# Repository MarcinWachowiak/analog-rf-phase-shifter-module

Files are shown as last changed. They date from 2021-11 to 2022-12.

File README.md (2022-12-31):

# Analog RF phase shifter module
<div align="justify">
Analog RF phase shifter modules for 2.45 GHz or 5.8 GHz. Phase shift range up to 360° for input voltage of 0 - 3.3V

**There is a discrepancy between the simulation results and testbed measurements. 
A more detailed analysis of parasitics and fine-tuning of component values is advised.**
</div>

  - **2.45 GHz distributed components version**

    **Manufactured prototypes:**

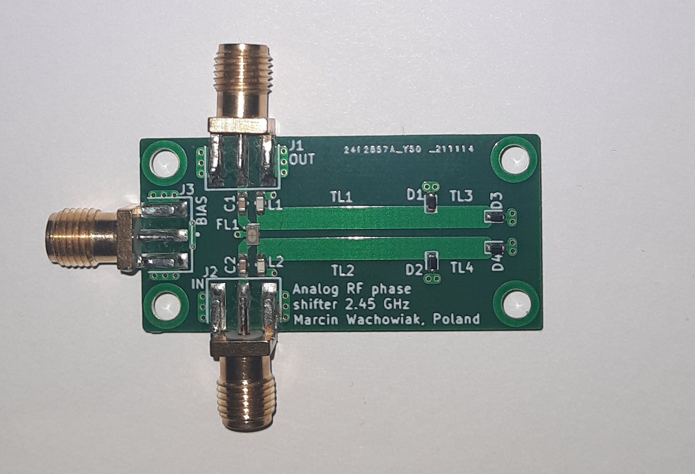
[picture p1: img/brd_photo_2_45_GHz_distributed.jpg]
brd_photo
    

    **PCB:**
    
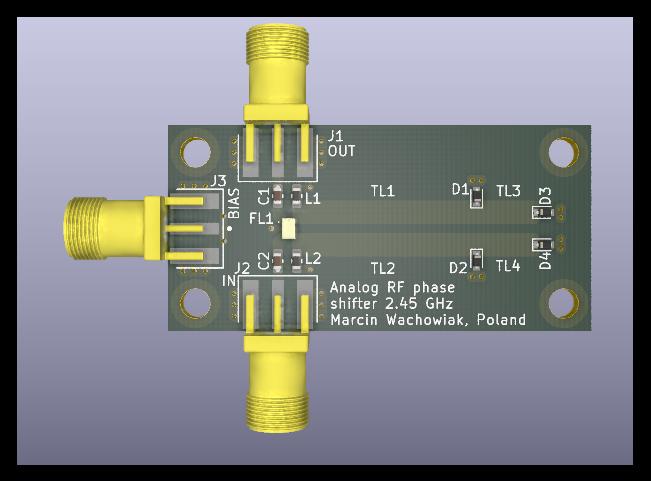
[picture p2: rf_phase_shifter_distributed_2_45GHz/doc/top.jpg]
    
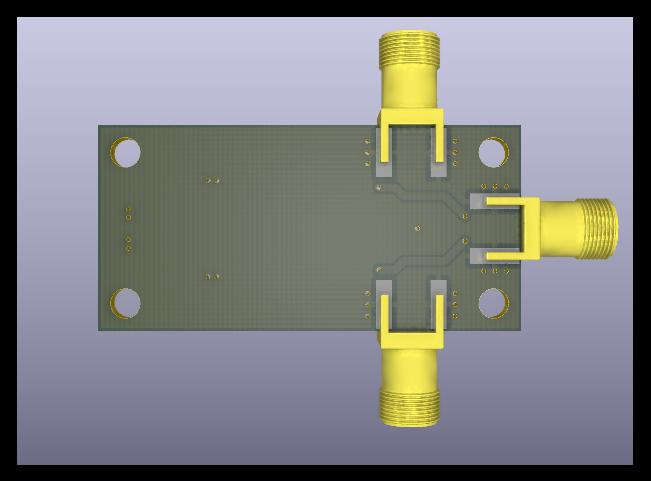
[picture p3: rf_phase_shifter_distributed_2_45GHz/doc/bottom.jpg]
2_45GHz_bottom
    

    **Simualtion results:**
    
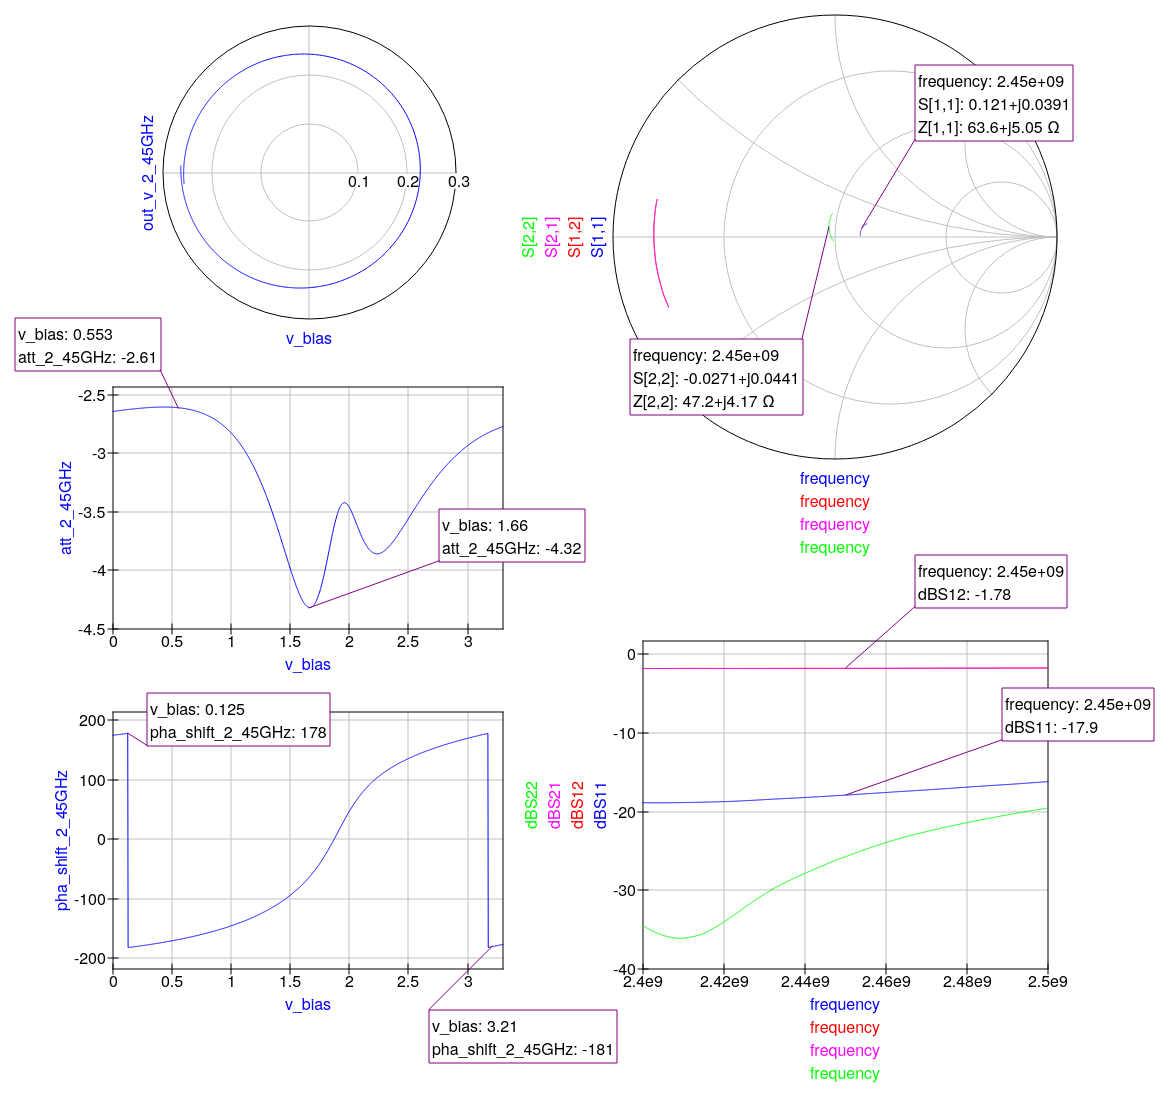
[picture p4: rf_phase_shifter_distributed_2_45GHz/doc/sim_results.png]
simulation_results_2_45GHz
    

    <br>

  - **2.45 GHz discrete components version**

    **Manufactured prototypes:**

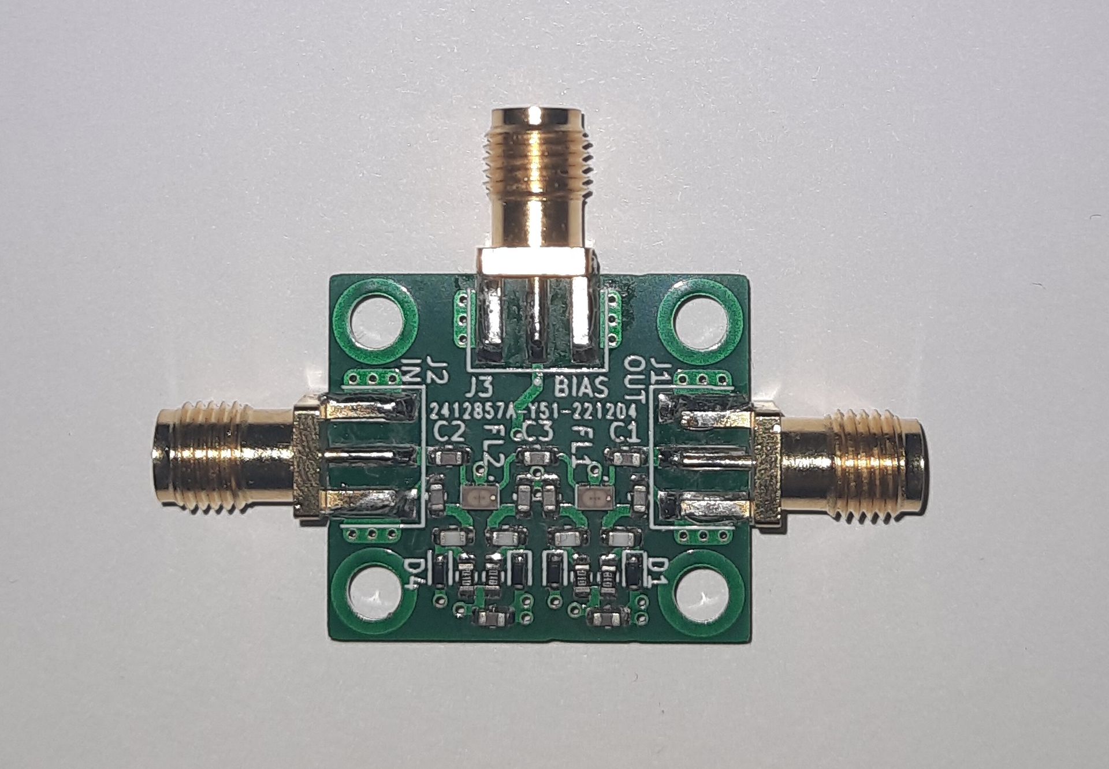
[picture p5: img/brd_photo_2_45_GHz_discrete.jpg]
brd_photo
    

    **PCB:**
    
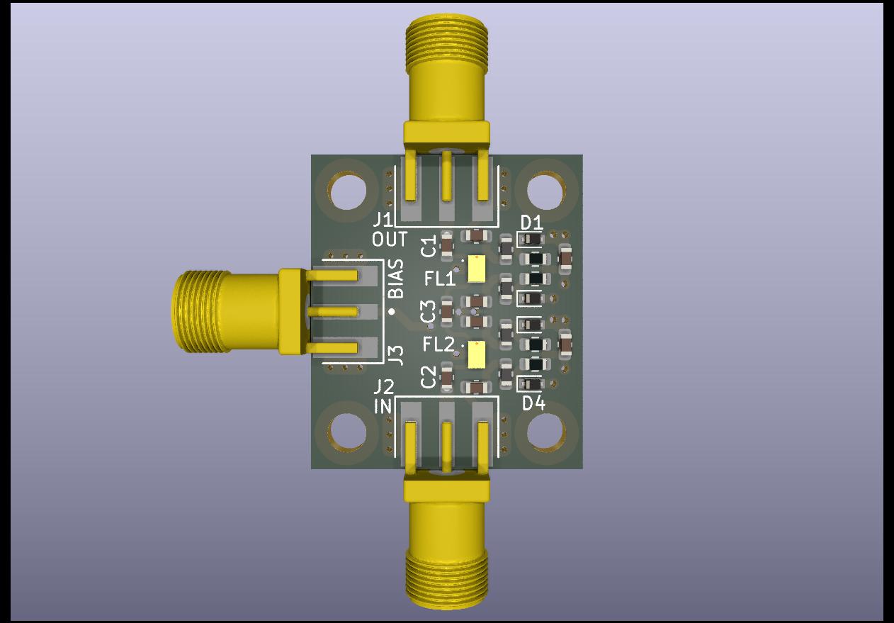
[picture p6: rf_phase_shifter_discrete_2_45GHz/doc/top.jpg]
    
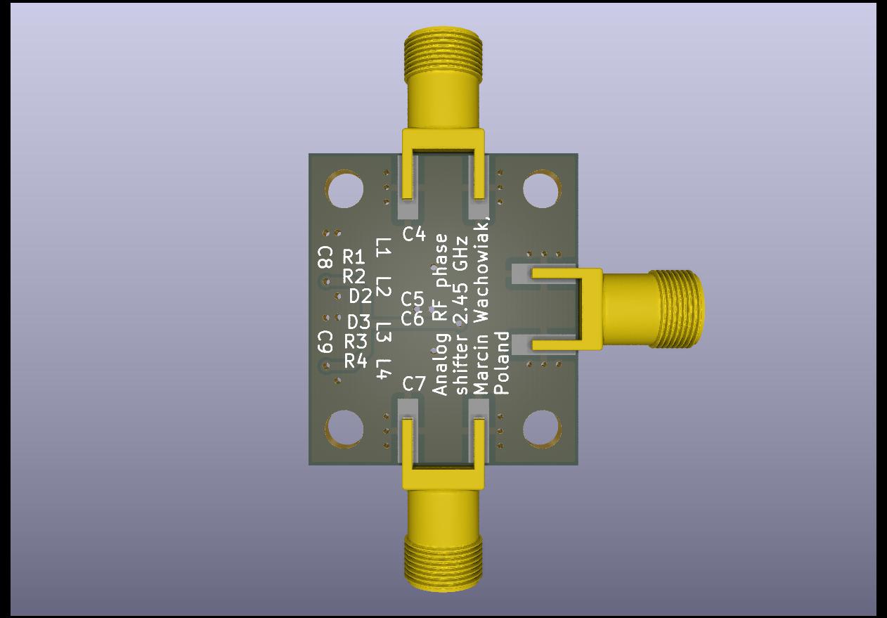
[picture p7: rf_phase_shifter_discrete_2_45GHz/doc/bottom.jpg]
2_45GHz_bottom
    

    **Simualtion results:**
    
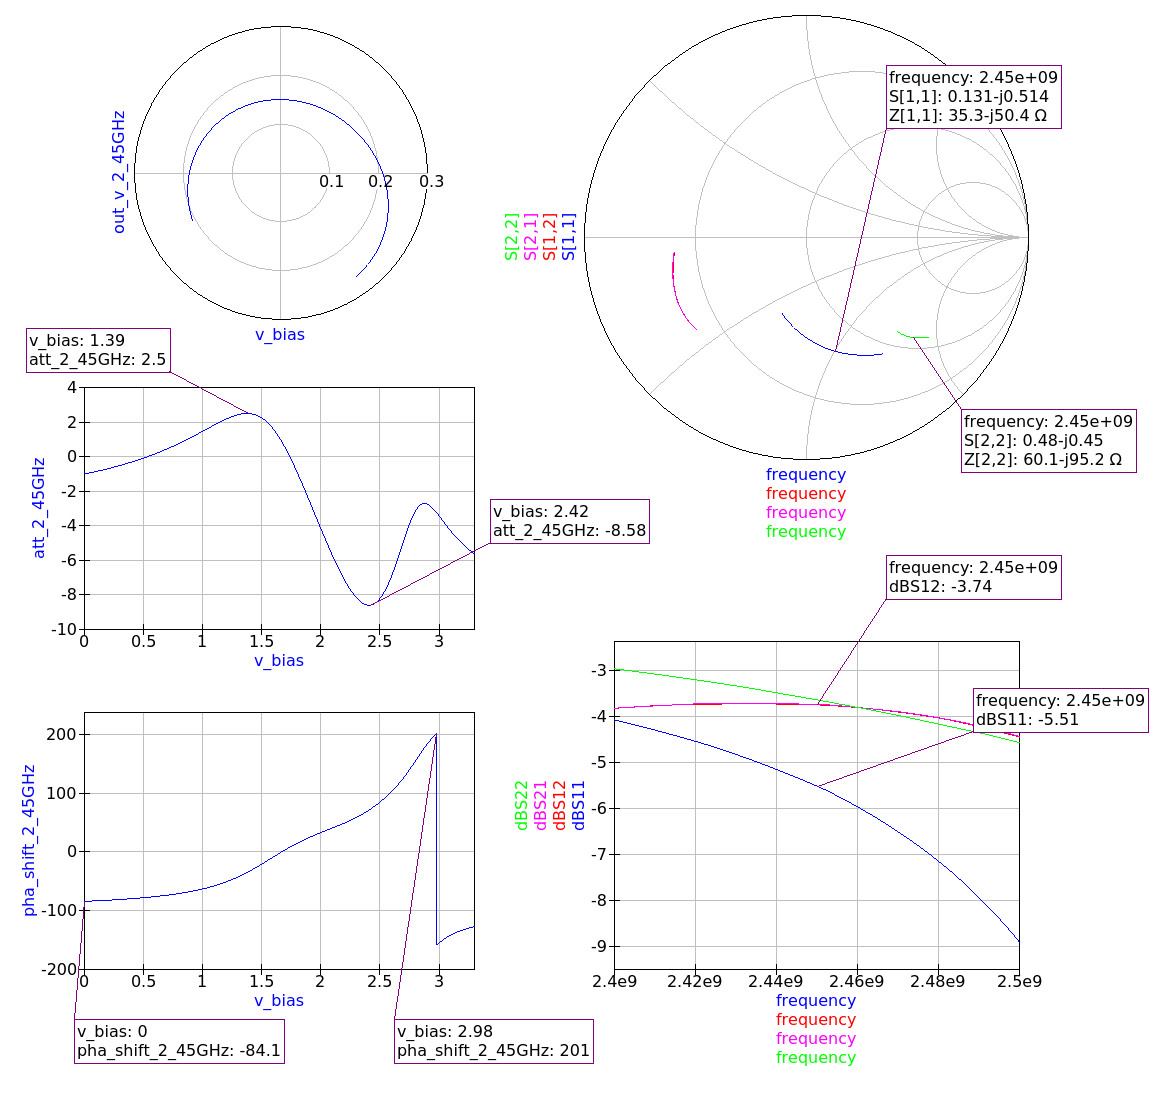
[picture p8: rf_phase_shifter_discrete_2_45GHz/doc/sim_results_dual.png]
simulation_results_2_45GHz
    

    <br>

  - **5.8 GHz distributed components version**

    **Manufactured prototypes:**

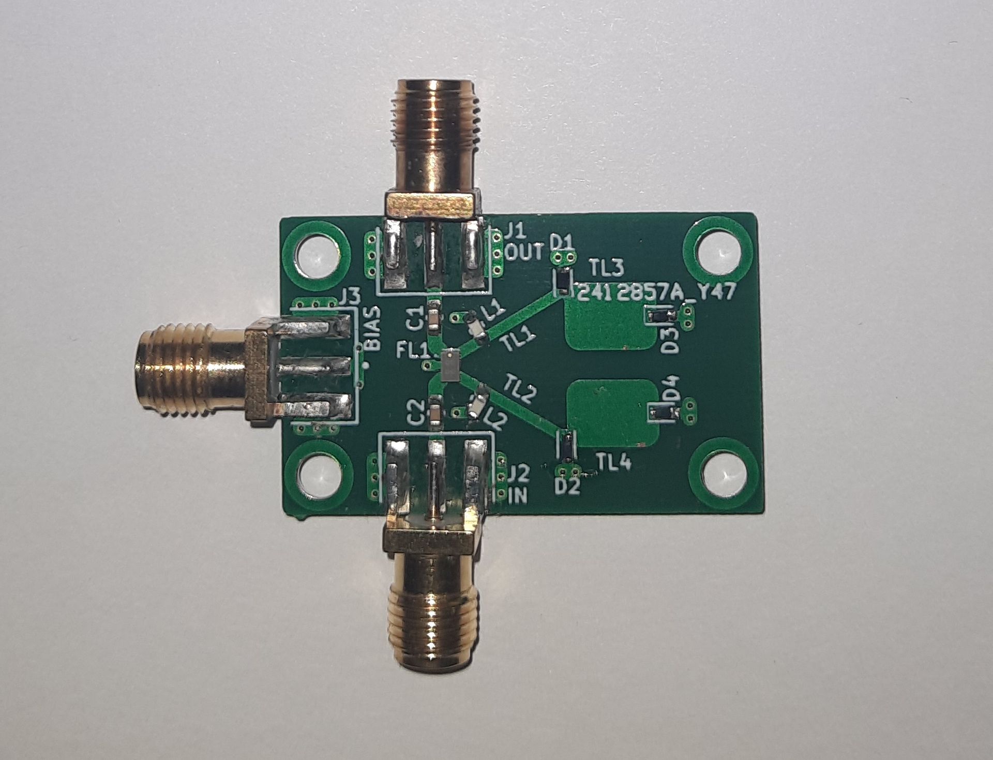
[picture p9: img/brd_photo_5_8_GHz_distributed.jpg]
brd_photo
    

    **PCB:**
    
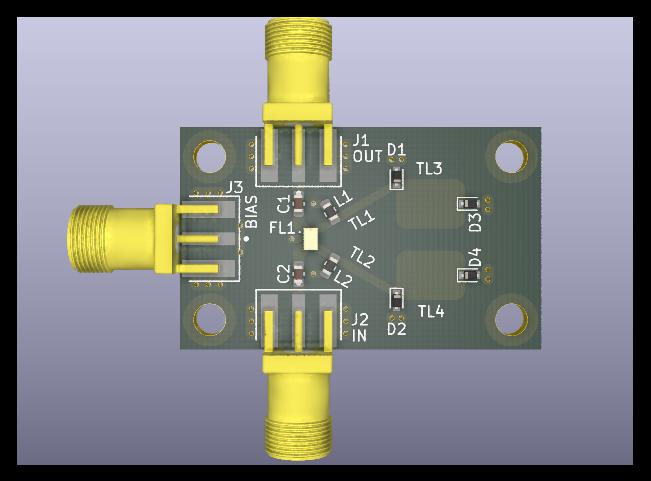
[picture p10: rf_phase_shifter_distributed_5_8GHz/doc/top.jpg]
5_8GHz_top
    
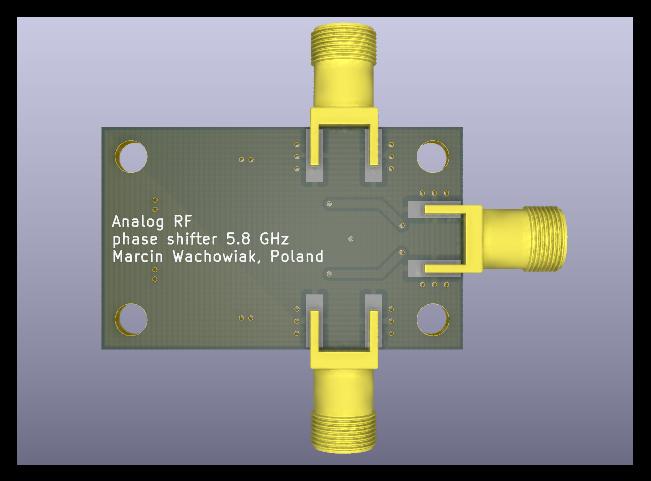
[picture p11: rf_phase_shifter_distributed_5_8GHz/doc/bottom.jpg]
5_8GHz_bottom
    

    **Simualtion results:**

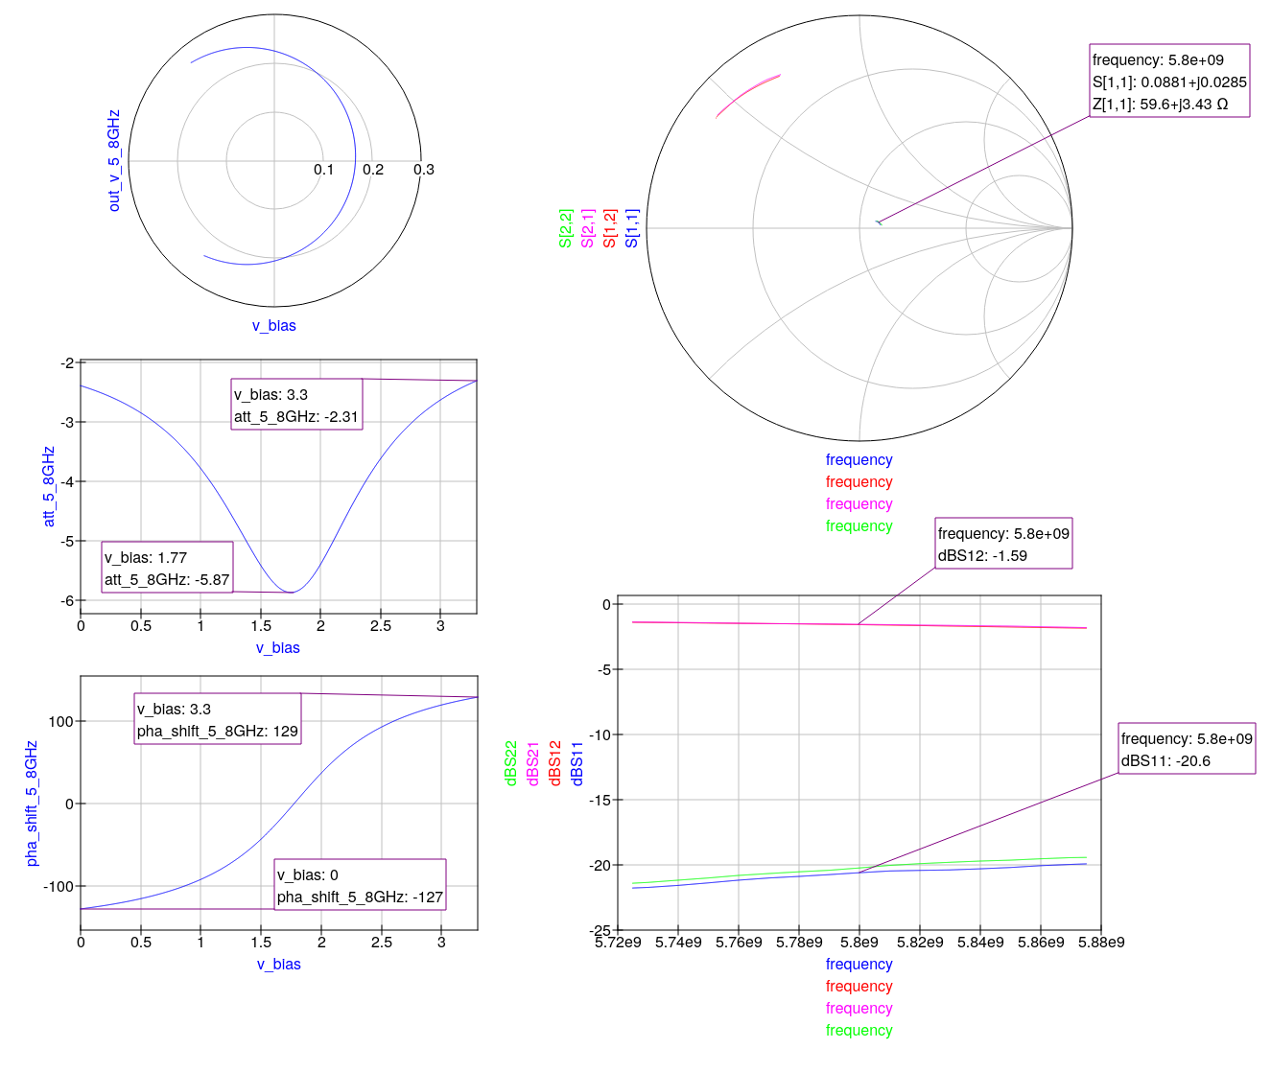
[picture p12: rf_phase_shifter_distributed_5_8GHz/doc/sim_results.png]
simulation_results_5_8GHz


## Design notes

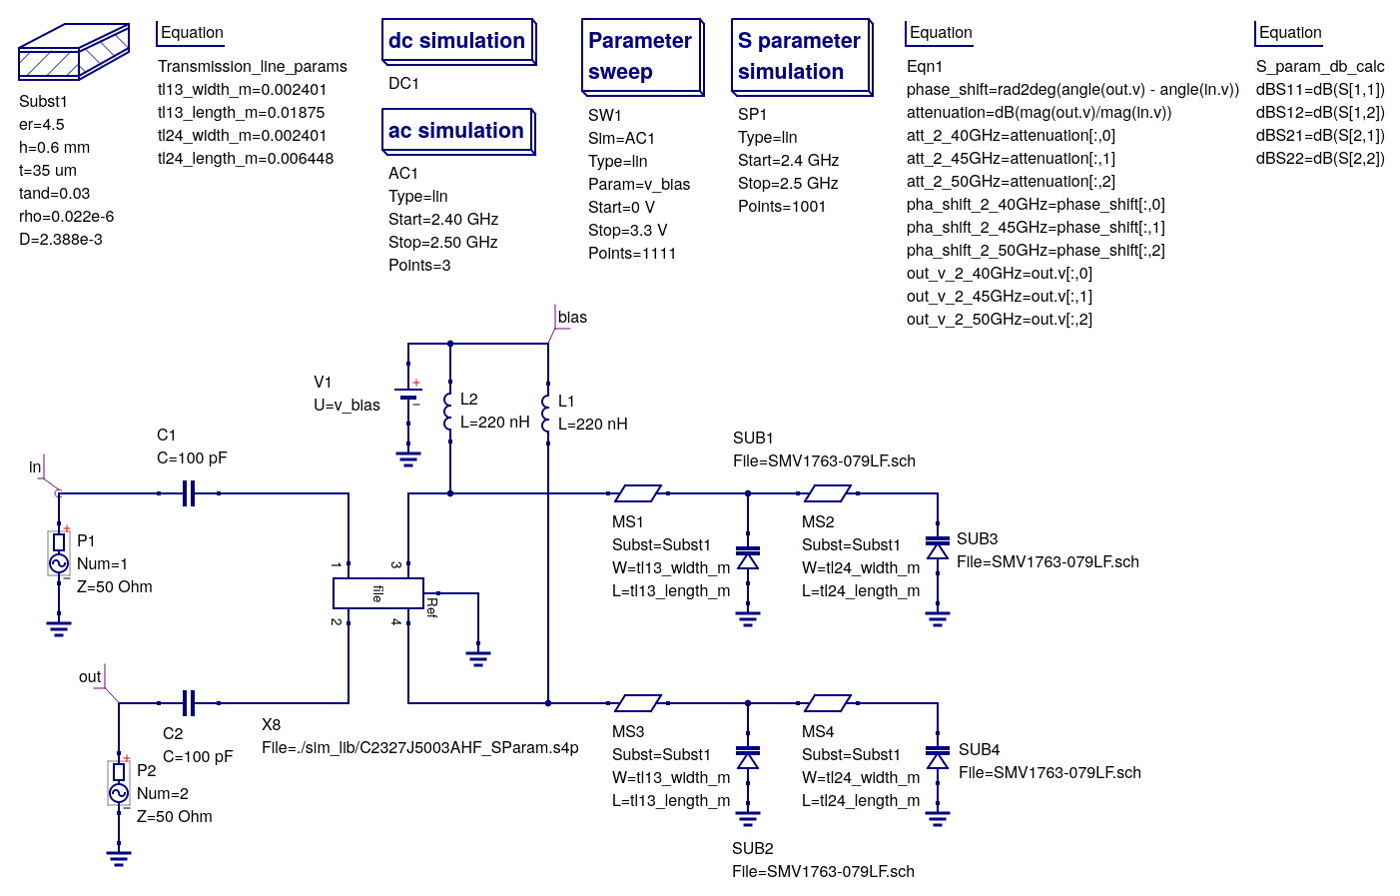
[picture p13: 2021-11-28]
rf_phase_shifter_distributed_2_45GHz/doc/sim_sch.png

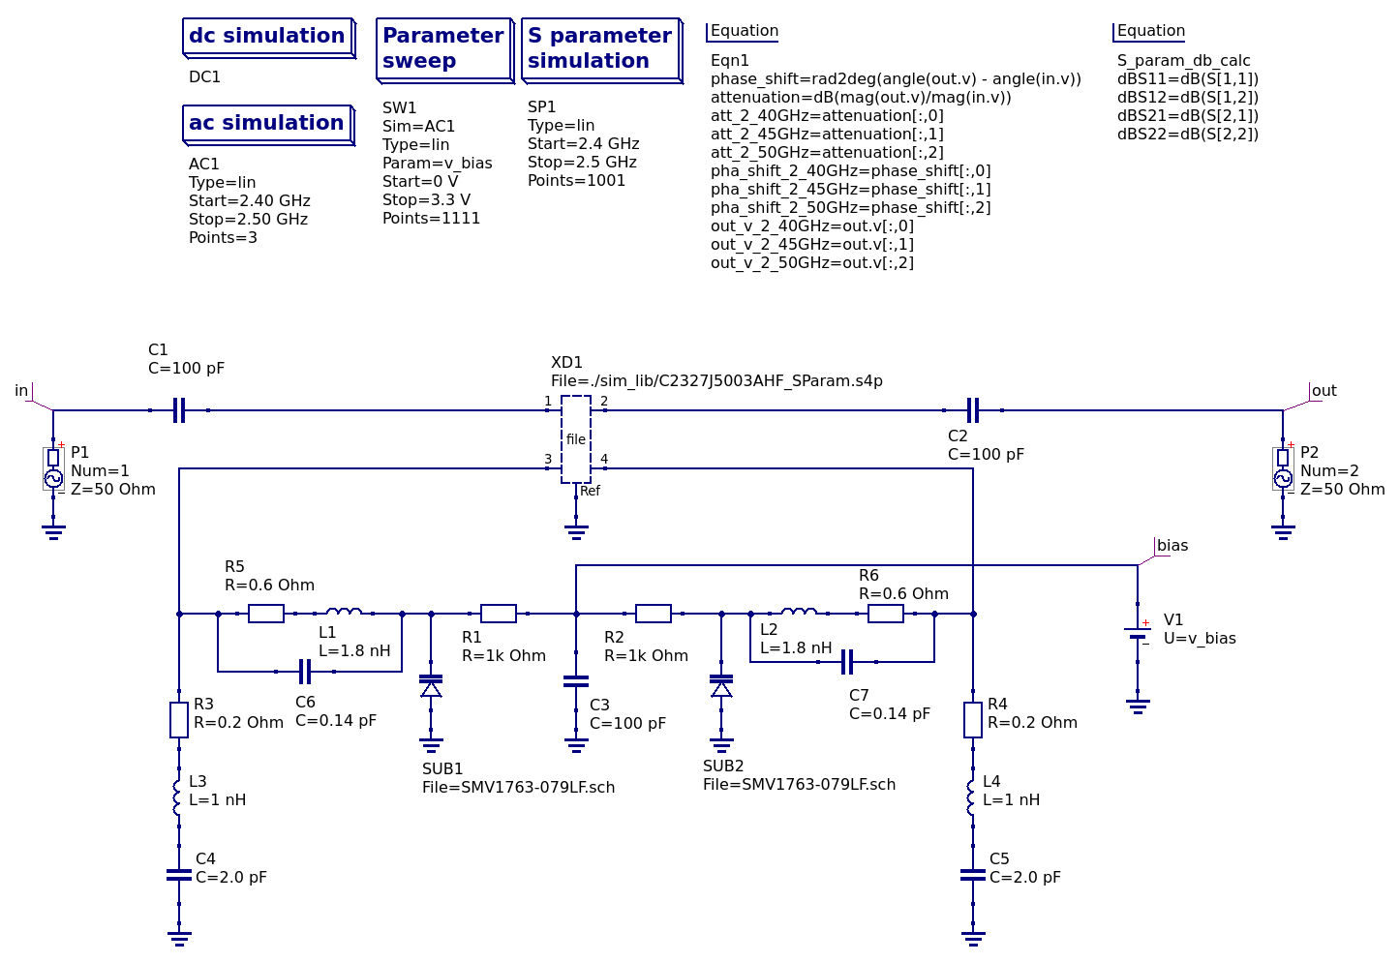
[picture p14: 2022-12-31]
rf_phase_shifter_discrete_2_45GHz/doc/sim_sch_single.png

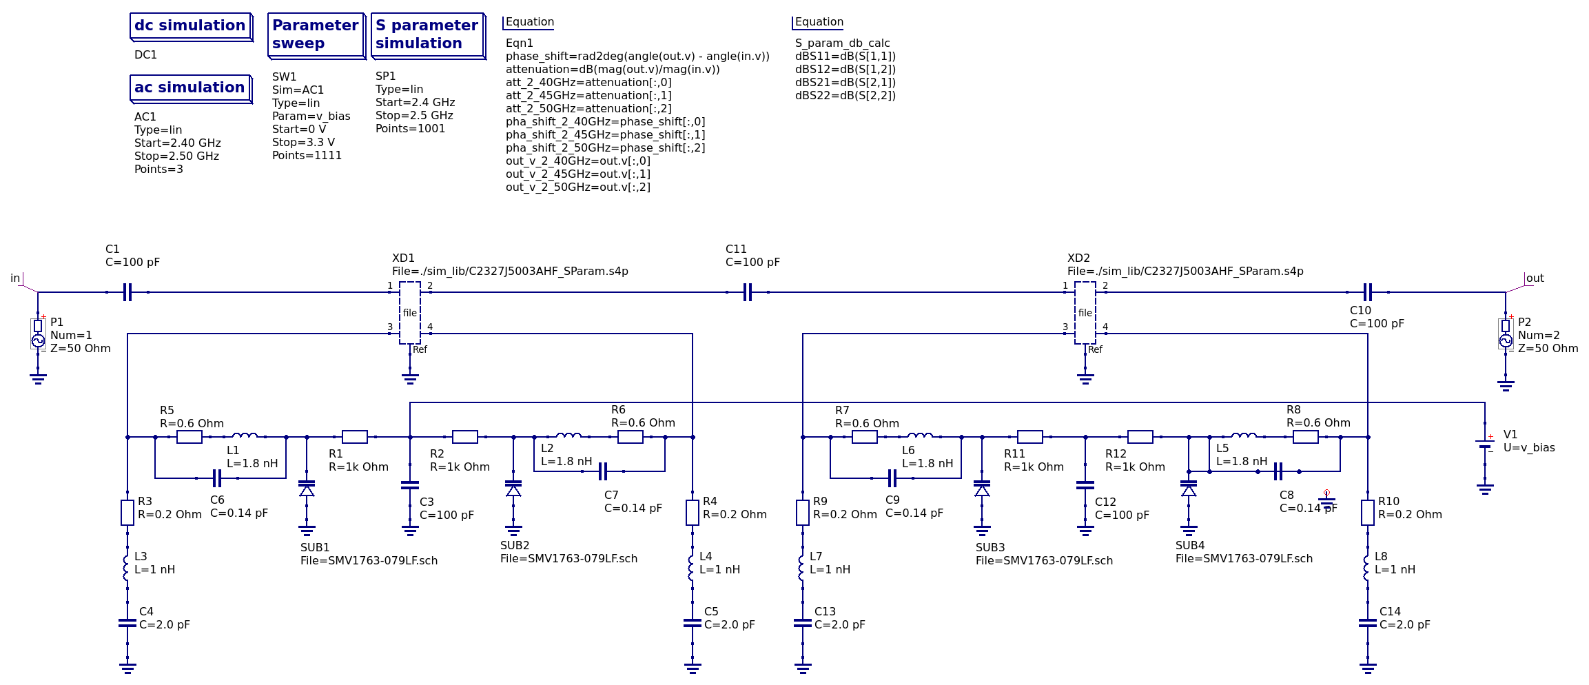
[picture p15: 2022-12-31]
rf_phase_shifter_discrete_2_45GHz/doc/sim_sch_dual.png

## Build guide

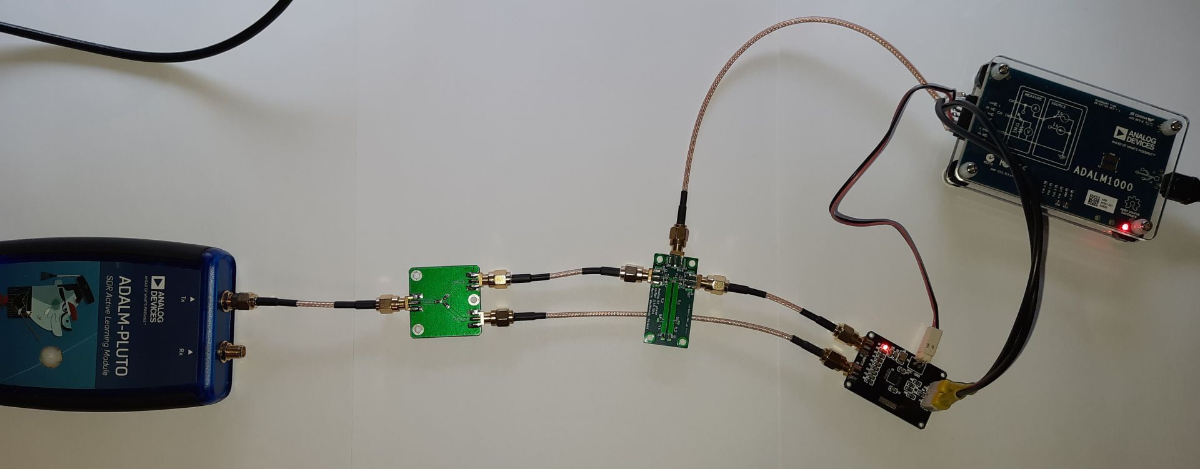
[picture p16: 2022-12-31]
testbench/img/testbed_setup_distributed_2_45_GHz.jpg

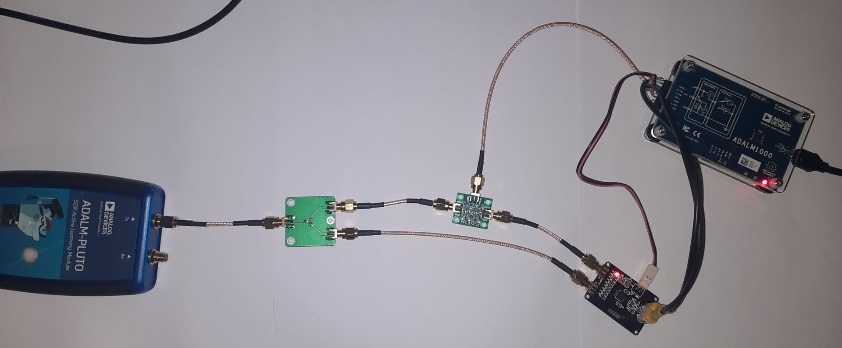
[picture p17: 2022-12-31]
testbench/img/testbed_setup_discrete_2_45_GHz.jpg

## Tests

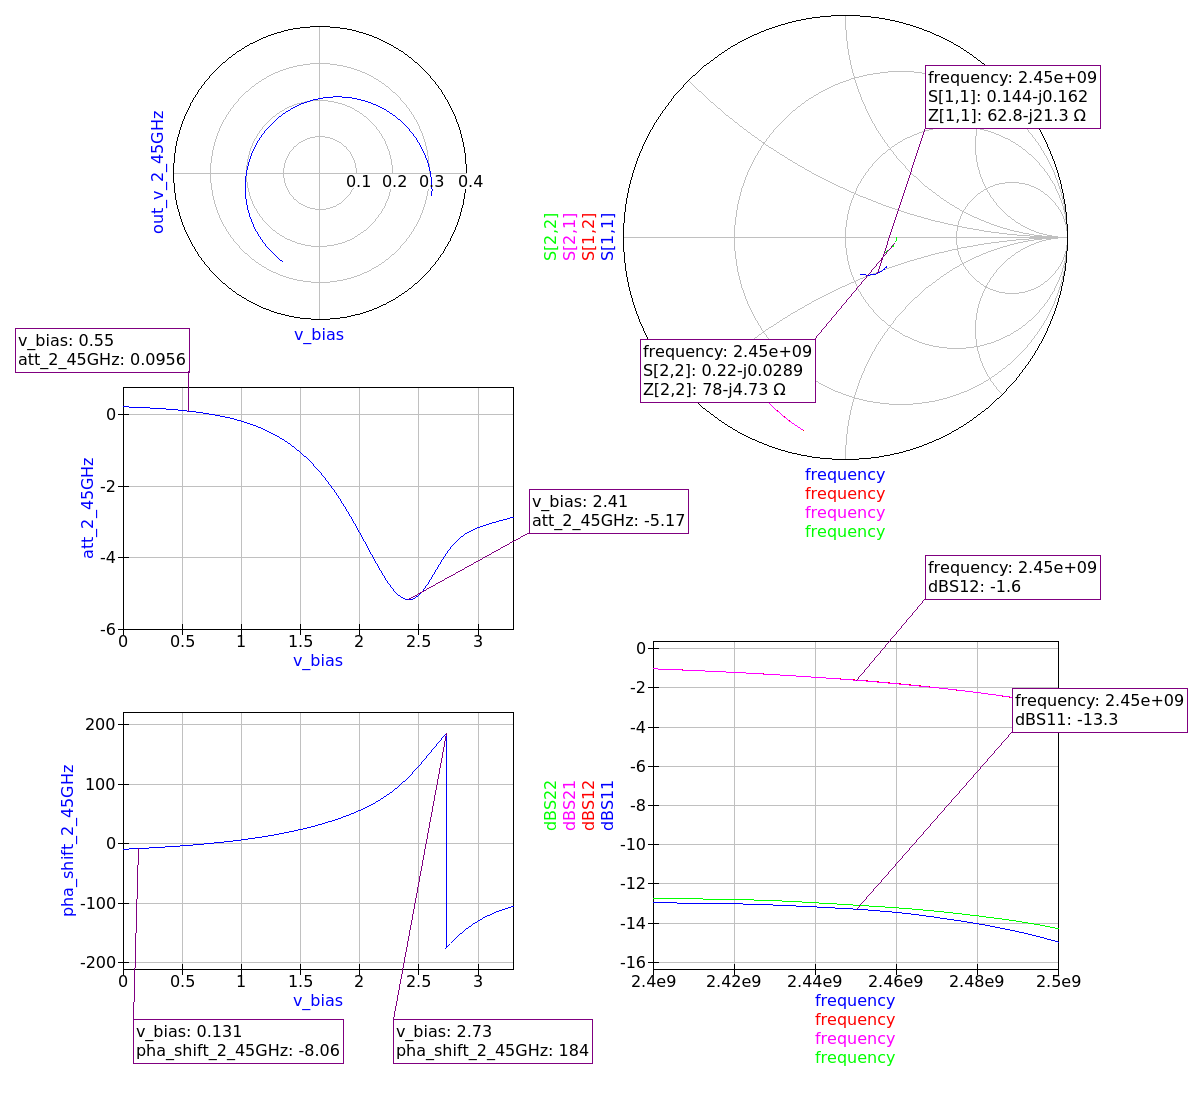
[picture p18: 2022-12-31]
rf_phase_shifter_discrete_2_45GHz/doc/sim_results_single.png

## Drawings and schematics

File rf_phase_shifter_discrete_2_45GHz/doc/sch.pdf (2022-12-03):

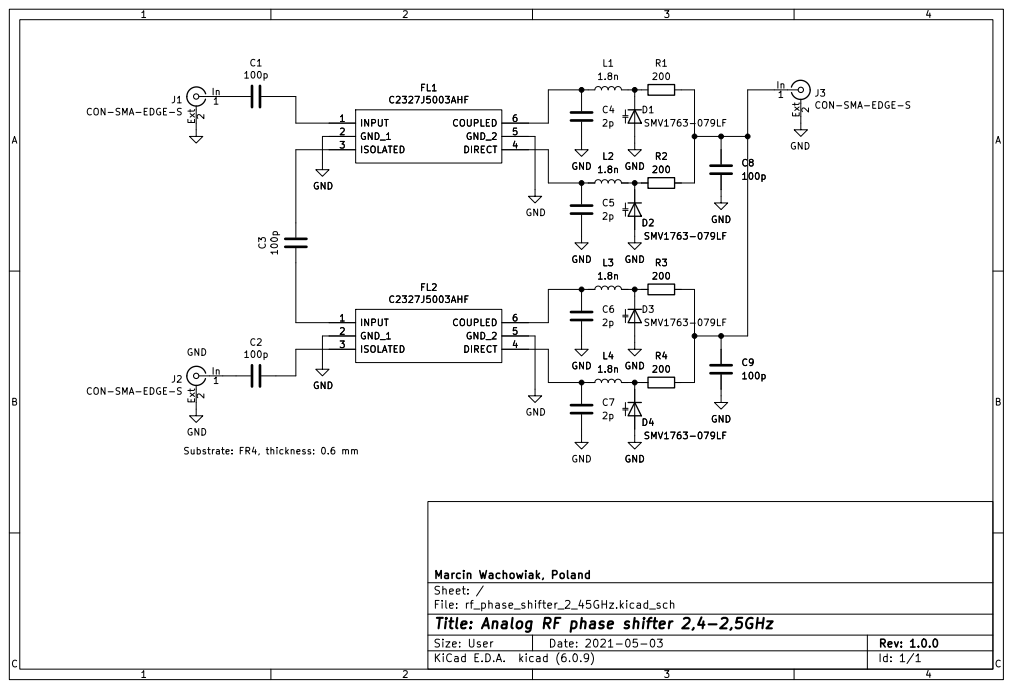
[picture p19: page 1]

File: rf_phase_shifter_2_45GHz.kicad_sch Sheet: / Marcin Wachowiak, PolandGND

Id: 1/1 Title: Analog RF phase shifter 2,4-2,5GHz

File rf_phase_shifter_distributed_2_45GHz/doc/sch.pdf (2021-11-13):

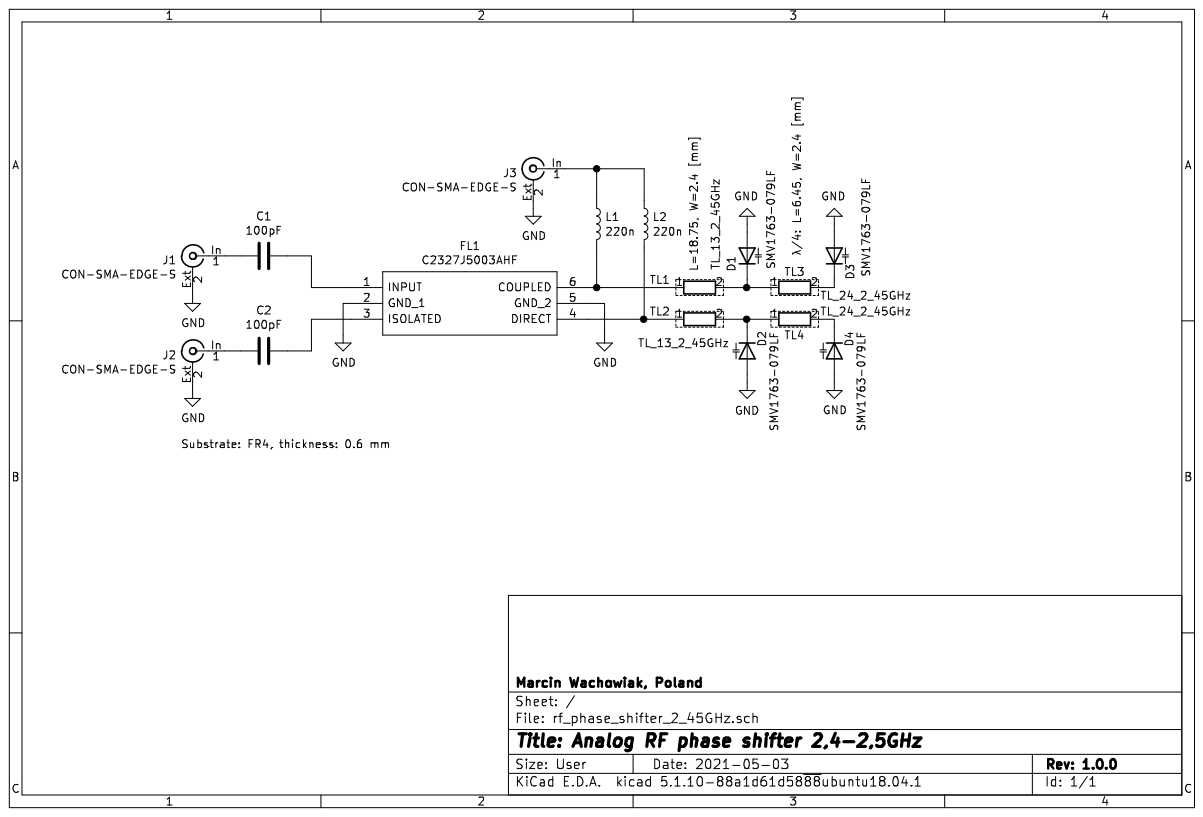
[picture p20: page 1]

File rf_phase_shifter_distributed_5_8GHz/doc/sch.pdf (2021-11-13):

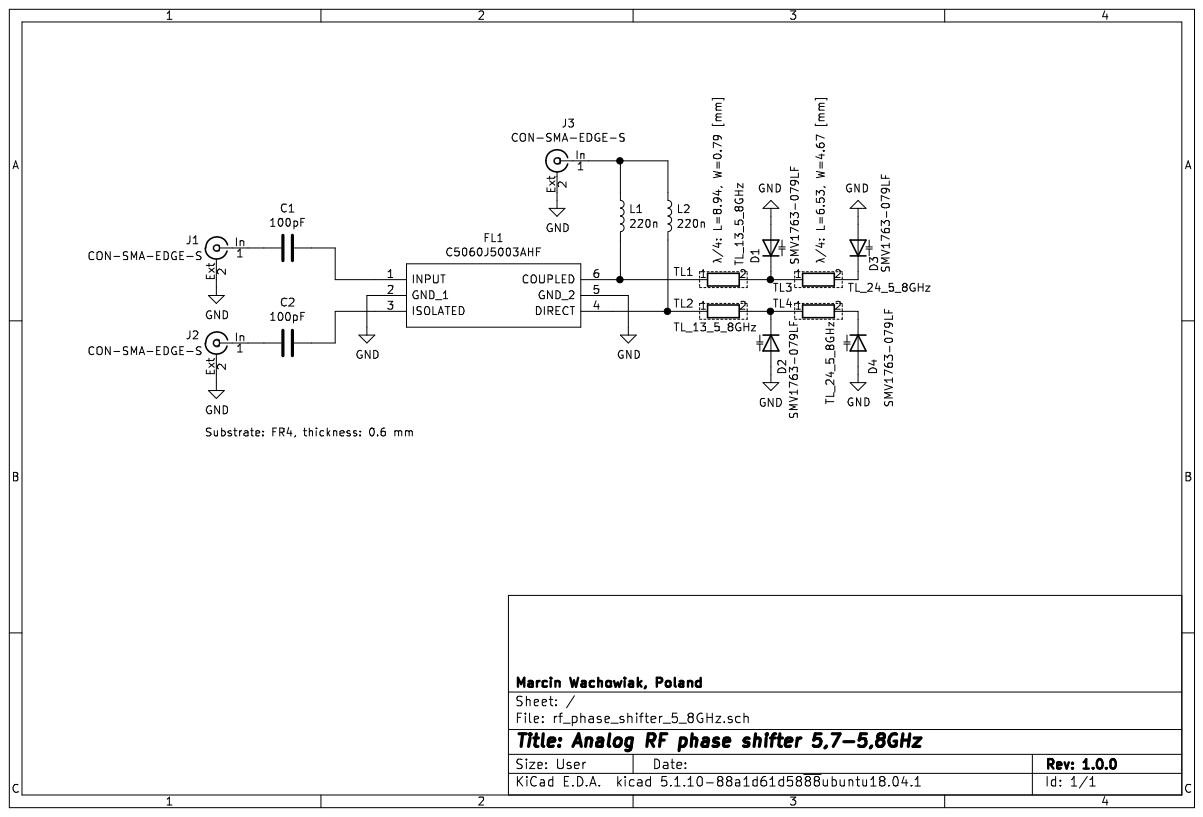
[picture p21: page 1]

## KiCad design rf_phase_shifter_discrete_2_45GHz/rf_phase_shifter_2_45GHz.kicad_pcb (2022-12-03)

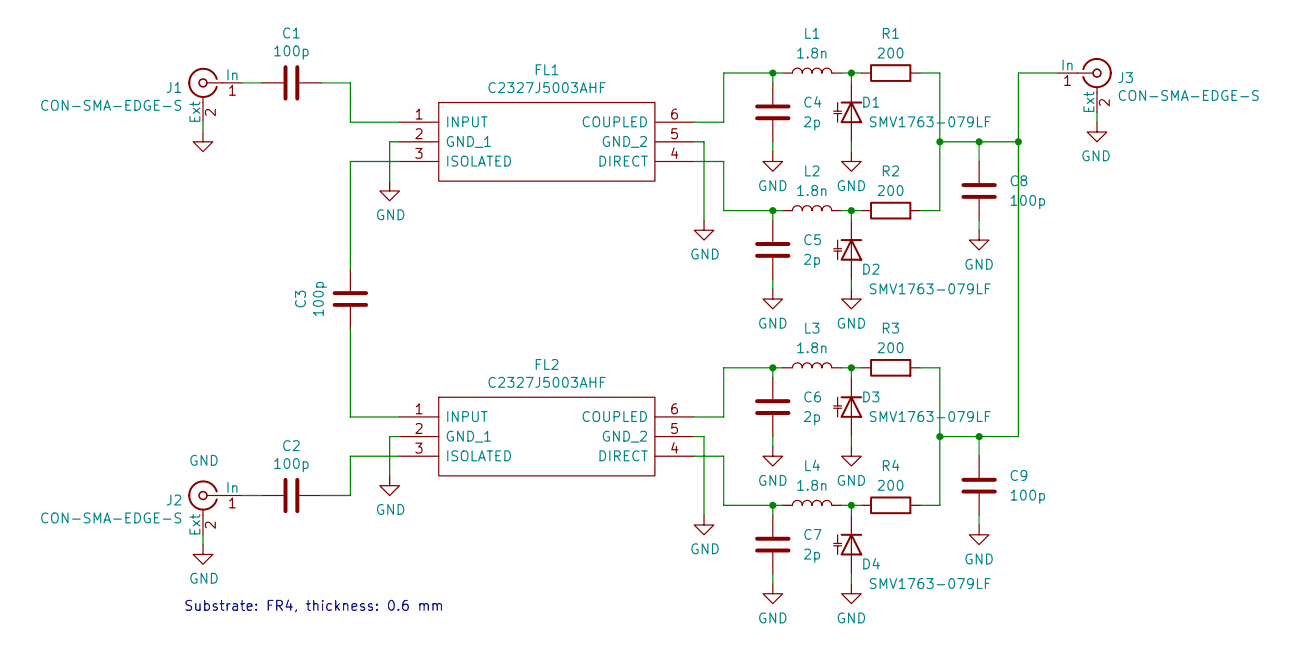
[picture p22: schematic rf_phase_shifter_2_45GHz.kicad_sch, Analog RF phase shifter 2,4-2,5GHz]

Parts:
C1, C2, C3, C8, C9: 100p; C_0603_1608Metric
C4, C5, C6, C7: 2p; C_0603_1608Metric
D1, D2, D3, D4: SMV1763-079LF; D_SOD-523
FL1, FL2: C2327J5003AHF; Manufacturer_Part_Number C2327J5003AHF
J1, J2, J3: CON-SMA-EDGE-S; digikey description CONN SMA JACK STR EDGE MNT
L1, L2, L3, L4: 1.8n; L_0603_1608Metric
R1, R2, R3, R4: 200; R_0603_1608Metric

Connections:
GND: C4.2, C5.2, C6.2, C7.2, C8.2, C9.2, D1.2 (A), D2.2 (A), D3.2 (A), D4.2 (A), FL1.2 (GND_1), FL1.5 (GND_2), FL2.2 (GND_1), FL2.5 (GND_2), J1.2 (Ext), J2.2 (Ext), J3.2 (Ext)
unnamed: C1.1, FL1.1 (INPUT)
unnamed: C1.2, J1.1 (In)
unnamed: C2.1, J2.1 (In)
unnamed: C2.2, FL2.3 (ISOLATED)
unnamed: C3.1, FL2.1 (INPUT)
unnamed: C3.2, FL1.3 (ISOLATED)
unnamed: C4.1, FL1.6 (COUPLED), L1.1
unnamed: C5.1, FL1.4 (DIRECT), L2.1
unnamed: C6.1, FL2.6 (COUPLED), L3.1
unnamed: C7.1, FL2.4 (DIRECT), L4.1
unnamed: C8.1, C9.1, J3.1 (In), R1.2, R2.2, R3.2, R4.2
unnamed: D1.1 (K), L1.2, R1.1
unnamed: D2.1 (K), L2.2, R2.1
unnamed: D4.1 (K), L4.2, R4.1
unnamed: D3.1 (K), L3.2, R3.1

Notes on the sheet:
Substrate: FR4, thickness: 0.6 mm

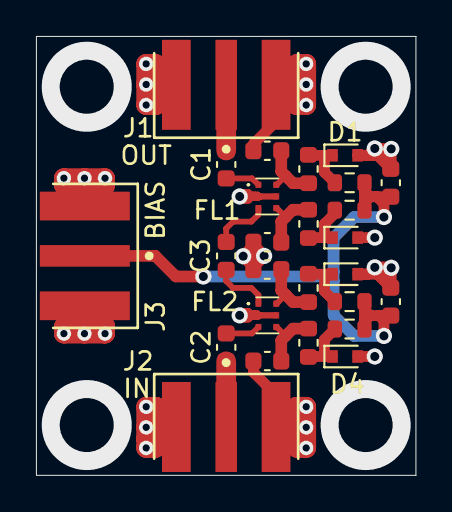
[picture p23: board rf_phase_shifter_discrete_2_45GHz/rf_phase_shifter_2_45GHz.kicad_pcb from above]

Board: 2 copper layers, 21.1 x 24.4 mm, 26 parts (0 on the bottom side), 16 nets.

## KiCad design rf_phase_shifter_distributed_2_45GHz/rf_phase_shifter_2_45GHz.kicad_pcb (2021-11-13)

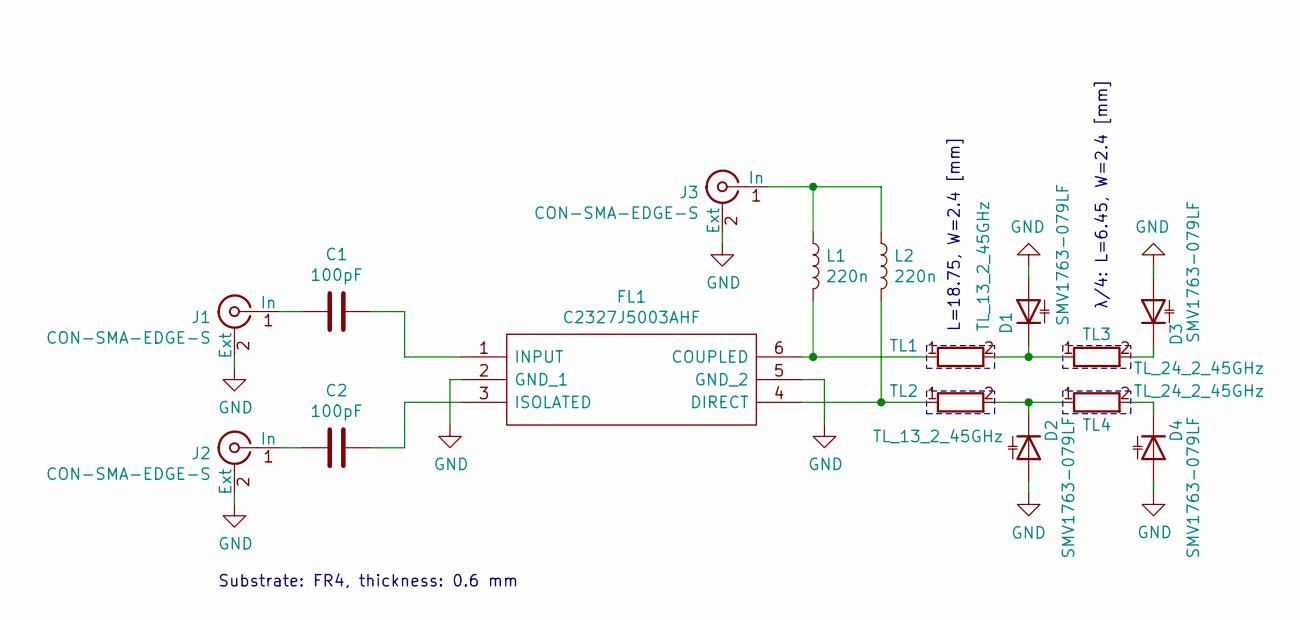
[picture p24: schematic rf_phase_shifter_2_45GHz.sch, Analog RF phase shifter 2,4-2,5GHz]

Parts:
C1, C2: 100pF; C_0603_1608Metric
D1, D2, D3, D4: SMV1763-079LF; D_SOD-523
FL1: C2327J5003AHF; Manufacturer_Part_Number C2327J5003AHF
J1, J2, J3: CON-SMA-EDGE-S; digikey description CONN SMA JACK STR EDGE MNT
L1, L2: 220n; L_0603_1608Metric
TL1, TL2: TL_13_2_45GHz
TL3, TL4: TL_24_2_45GHz

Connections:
GND: D1.2 (A), D2.2 (A), D3.2 (A), D4.2 (A), FL1.2 (GND_1), FL1.5 (GND_2), J1.2 (Ext), J2.2 (Ext), J3.2 (Ext)
unnamed: C1.1, FL1.1 (INPUT)
unnamed: C1.2, J1.1 (In)
unnamed: C2.1, J2.1 (In)
unnamed: C2.2, FL1.3 (ISOLATED)
unnamed: D1.1 (K), TL1.2, TL3.1
unnamed: D2.1 (K), TL2.2, TL4.1
unnamed: D3.1 (K), TL3.2
unnamed: D4.1 (K), TL4.2
unnamed: FL1.4 (DIRECT), L2.2, TL2.1
unnamed: FL1.6 (COUPLED), L1.2, TL1.1
unnamed: J3.1 (In), L1.1, L2.1

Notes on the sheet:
L=18.75, W=2.4 [mm]
λ/4: L=6.45, W=2.4 [mm]
Substrate: FR4, thickness: 0.6 mm

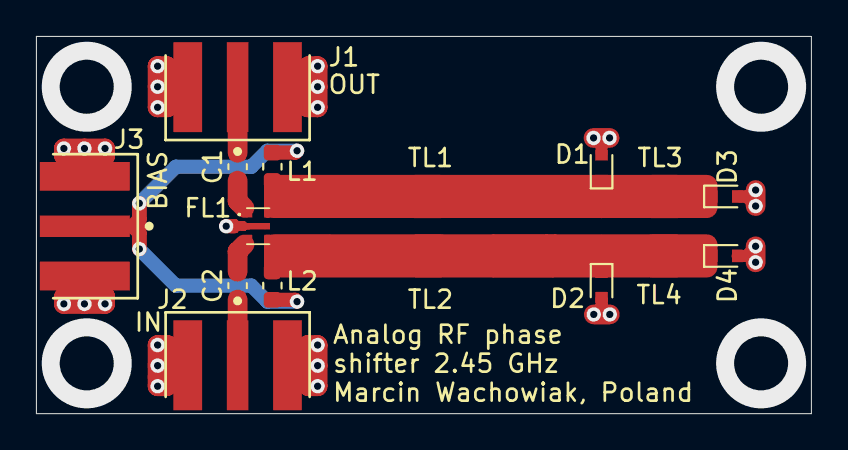
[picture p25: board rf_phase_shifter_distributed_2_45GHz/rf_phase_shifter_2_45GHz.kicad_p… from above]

Board: 2 copper layers, 43.1 x 21.0 mm, 16 parts (0 on the bottom side), 12 nets.

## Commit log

2021-04-01 Finished sch
    [rf_phase_shifter_2_45GHz.kicad_pcb, rf_phase_shifter_2_45GHz.sch, rf_phase_shifter_5_8GHz.kicad_pcb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]
2021-04-16 Update rf_phase_shifter_2_45GHz.kicad_pcb
    update
    [rf_phase_shifter_2_45GHz.kicad_pcb]
2021-05-03 updated libs
    [rf_phase_shifter_2_45GHz.kicad_pcb, rf_phase_shifter_2_45GHz.sch, rf_phase_shifter_5_8GHz.kicad_pcb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]
2021-09-11 qucs sim
    [bby66-02v-sc79.sch, rf_phase_shifter_2_45GHz.sch]
2021-09-15 added s4p models for couplers
    [rf_phase_shifter_2_45GHz.sch]
2021-09-26 finished impedance tuning
    [rf_phase_shifter_2_45GHz.sch, rf_phase_shifter_5_8GHz.sch, tl13_impedance_tuning.sch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]
2021-09-26 finishing touches
    [rf_phase_shifter_2_45GHz.sch, rf_phase_shifter_5_8GHz.sch]
2021-09-26 pcb init works
    [rf_phase_shifter_2_45GHz.kicad_pcb, rf_phase_shifter_2_45GHz.sch, rf_phase_shifter_5_8GHz.kicad_pcb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]
2021-09-27 finished pcb layouts
    [rf_phase_shifter_2_45GHz-B_Cu.gbr, rf_phase_shifter_2_45GHz-B_Mask.gbr, rf_phase_shifter_2_45GHz-B_Paste.gbr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]
2021-09-27 added pcb images
    [rf_phase_shifter_2_45GHz-B_Cu.gbr, rf_phase_shifter_2_45GHz-B_Mask.gbr, rf_phase_shifter_2_45GHz-B_Paste.gbr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]
2021-09-27 fabrication fixes
    [rf_phase_shifter_2_45GHz-B_Cu.gbl, rf_phase_shifter_2_45GHz-B_Mask.gbr, rf_phase_shifter_2_45GHz-B_Mask.gbs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]
2021-10-23 added info about substrate thickness
    [rf_phase_shifter_2_45GHz.kicad_pcb, rf_phase_shifter_2_45GHz.sch, rf_phase_shifter_5_8GHz.kicad_pcb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]
2021-11-01 Replaced unreal BBY66 model
    [BBY65-02V-SC79.sch, BBY66-02V-SC79.sch, SMV1245-079LF.sch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]
2021-11-13 finished optimizing 2.4GHZ PH
    [rf_phase_shifter_2_45GHz.sch, rf_phase_shifter_5_8GHz.sch, tl13_impedance_tuning.sch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]
2021-11-13 finished 5.5GHZ PH optimization
    [SMV1763-079LF.sch, rf_phase_shifter_5_8GHz.sch, tl13_impedance_tuning.sch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]
2021-11-13 Finished layout of second prototypes
    [rf_phase_shifter_2_45GHz-B_Cu.gbl, rf_phase_shifter_2_45GHz-B_Mask.gbs, rf_phase_shifter_2_45GHz-B_Paste.gbp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]
2021-11-28 Added init testbench and simulation images
    [rf_phase_shifter_2_45GHz.sch]
2022-11-19 Prepare repo for discrete component version
    [SMV1763-079LF.sch, diode_reactance_meas.sch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]
2022-11-22 prepare qucs sim files for new schematic
    [SMV1763-079LF.sch, diode_reactance_meas.sch, rf_phase_shifter_2_45GHz.sch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]
2022-11-22 Initial tests after installing QUCS
    [SMV1763-079LF.sch, rf_phase_shifter_2_45GHz.sch]
2022-11-25 Fixed schematic, added parasitics and initial LC sweeps
    [SMV1763-079LF.sch, c_par_tuning.m.cfg, c_par_tuning.sch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]
2022-12-02 added simultaneous C and L tuning
    [l_ser_and_c_par_tuning.m.cfg, l_ser_and_c_par_tuning.sch, rf_phase_shifter_2_45GHz.sch]
2022-12-03 update simulations
    [l_ser_and_c_par_tuning.sch, rf_phase_shifter_2_45GHz.sch]
2022-12-03 Designed pcb for discrete component version, generated gerbers and updated docs
    [rf_phase_shifter_2_45GHz-B_Cu.gbl, rf_phase_shifter_2_45GHz-B_Mask.gbs, rf_phase_shifter_2_45GHz-B_Paste.gbp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]
2022-12-10 update gitignore not to track jupyter checkpoints
2022-12-31 Added testbench results of manufactured prototypes
2022-12-31 Updated readme with new prototype
2022-12-31 rearange simulation files and add result img
    [l_ser_and_c_par_tuning.sch, rf_phase_shifter_2_45GHz_dual.sch, rf_phase_shifter_2_45GHz_single.sch]
